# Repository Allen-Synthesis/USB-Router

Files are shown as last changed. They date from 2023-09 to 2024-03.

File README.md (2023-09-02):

# USB Router
### A module to route a USB signal between the front and back of your Eurorack system with optional +5V rail power

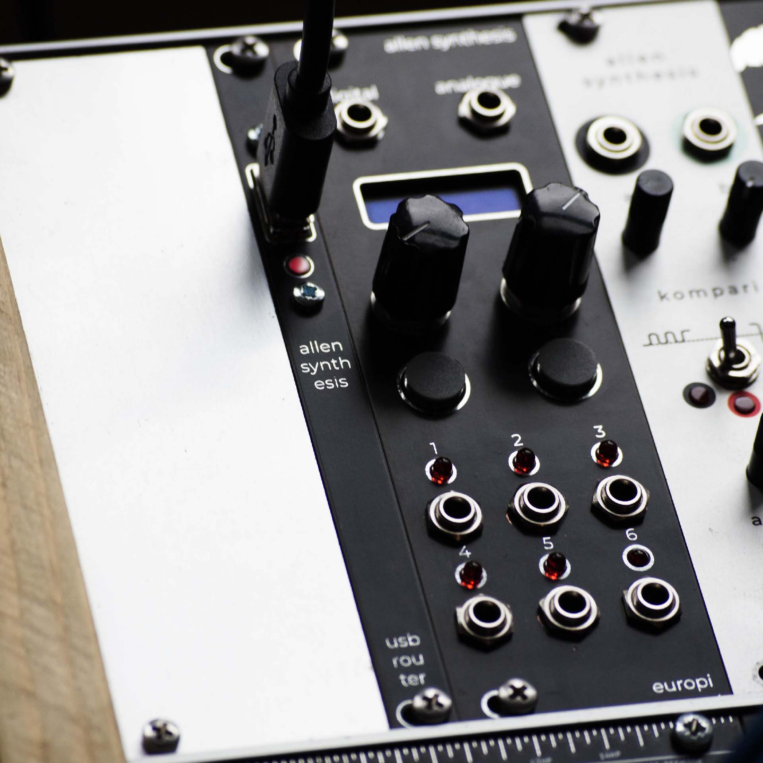
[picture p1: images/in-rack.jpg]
module in rack


The USB Router features one USB-A socket on the front, and an identical USB-A socket on the back.  
The power and data lines of the two sockets are always connected to each other, so you can always use the module for its most basic functions - programming Eurorack modules which feature USB connectors on the back.

### +5V Rail Power
There is a solder jumper on the rear of the USB Router which, if bridged with solder, will power both the front and back USB sockets using the +5V rail of your Eurorack system. This connection happens through a Schottky diode with a small voltage drop, so your +5V rail is still protected from reverse powering via the USB sockets (plugging a USB cable in which supplies +5V can never power the +5V rail of your system, only the other way around).  
This feature allows you to use the USB Router to power 5V devices, for example MIDI keyboards or lighting, or even to charge your phone.

### Potential Uses
- Programming or updating [EuroPi](https://github.com/Allen-Synthesis/EuroPi) modules or other USB supporting modules such as [Uncertainty](https://oamodular.org/products/uncertainty) by OA Modular, without needing to remove them from the rack
- Powering a MIDI keyboard such as an Arturia Keystep
- Configuring a MIDI keyboard, for example the Arturia Keystep without having to rearrange your whole setup

### LICENSES
Hardware: [CERN-OHL-S-2.0](https://spdx.org/licenses/CERN-OHL-S-2.0.html)  
Documentation: [CC0](https://creativecommons.org/share-your-work/public-domain/cc0/)

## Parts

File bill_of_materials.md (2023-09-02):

| Component | Quantity | Link | Notes |
| --- | --- | ---- | ----- |
| Panel + PCB | 1 | [Allen Synthesis](https://allensynthesis.square.site/product/usb-router/22)  | This can be bought as part of a Panel + PCB kit from the [Allen Synthesis website](https://www.allensynthesis.co.uk) or ordered using the KiCad files in this repository |
| USB-A Connector | 2 | [CPC](https://cpc.farnell.com/multicomp/usb-a-s-vt/usb-2-0-type-a-receptacle-th/dp/CN22155?ost=cn22155), [Mouser](https://www.mouser.co.uk/ProductDetail/CUI-Devices/UJ2-AV-1-TH?qs=5mqXD9RfOg2GaIS%2FC2TmTA%3D%3D) | Other vertical USB-A connectors may work, however only this one has been confirmed to fit on the PCB |
| Shrouded 16 Pin Header | 1 | [CPC](https://cpc.farnell.com/amphenol/t821116a1s100ceu/header-vertical-2-54mm-16way/dp/CN16429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), [CPC Alternative](https://cpc.farnell.com/wurth-elektronik/61201621621/header-2-54mm-vertical-16way/dp/CN17032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), [Thonk](https://www.thonk.co.uk/shop/eurorack-diy-essentials/), [Mouser](https://www.mouser.co.uk/ProductDetail/Wurth-Elektronik/61201621621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) | These headers are standard for Eurorack power connectors so can be bought from many different places |
| M3 13mm Standoff | 2 | [CPC](https://cpc.farnell.com/ettinger/05-03-133/spacer-m3x13-ni/dp/PC02612?st=13mm%20standoff), [Mouser](https://www.mouser.co.uk/ProductDetail/Wurth-Elektronik/970130321?qs=wr8lucFkNMVzI4gY2uBL%252BQ%3D%3D) | Any M3 13mm standoff will work, made of pretty much any material. As long as your screws and standoff match in pitch and the length is 13mm, they'll work |
| M3 Screw | 4 (+ 2 more if you haven't already got some to mount the module to your rails) | [CPC (100 pack)](https://cpc.farnell.com/unbranded/m3x6-pan-pozi-stainl/m3x6-pan-pozi-stainless-screws/dp/FN00814?st=m3%20screw), [Mouser](https://www.mouser.co.uk/ProductDetail/Keystone-Electronics/9191-3?qs=wOxb8XianXjYu0m25ZR3Hw%3D%3D) | These are the same screws as you use to attach your modules to the rails, so if you already have them then there's no need to order more for this module |
| 3mm Flat Top LED | 1 | [CPC](https://cpc.farnell.com/kingbright/l-424idt/led-flat-top-3mm-he-red/dp/SC11543?st=kingbright%20led%203mm), [Thonk](https://www.thonk.co.uk/shop/new-style-flat-top-leds-turing-pulses-vactrol-mix/), [Mouser](https://www.mouser.co.uk/ProductDetail/Kingbright/WP424IDT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) | These don't have to be flat-top if you have any other 3mm LEDs (of any colour) but these are the only ones I have calculated the brightness for and tested in the module |
| 4.7k Resistor | 1 | [CPC (50 pack)](https://cpc.farnell.com/unbranded/mf25-4k7/resistor-0-25w-1-4k7/dp/RE03757?st=4k7%20resistor), [Mouser](https://www.mouser.co.uk/ProductDetail/Vishay-BC-Components/SFR2500004701JA500?qs=ClR5yMXwuUeHolVbK4G8uQ%3D%3D) | Any 4.7k resistor at all will do, of any reasonable tolerance. You can also use higher or lower values for brighter or dimmer LED appearance, but 4.7k with the LEDs listed in this bill of materials are the only ones which have been tested |
| Schottky Diode | 1 | [CPC](https://cpc.farnell.com/stmicroelectronics/bat48/diode-schottky-small-signal/dp/SC07328), [Mouser](https://www.mouser.co.uk/ProductDetail/Micro-Commercial-Components-MCC/1N5817-TP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) | This can be any Schottky diode which fits, however if you want the +5V rail to power the USB sockets with a high enough voltage to meet USB specifications, then a low voltage drop (the linked diode has an acceptable drop of 400mV) is required |
| USB-A to USB-A Cable | 1 | [CPC](https://cpc.farnell.com/pro-signal/psg91428/lead-usb2-0-a-male-a-male-grey/dp/CS30623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), [Mouser](https://www.mouser.co.uk/ProductDetail/Qualtek/3021059-01M?qs=MLItCLRbWsylgGXE0uMn3Q%3D%3D) | This is completely optional, but if you want to use the USB Router to program a EuroPi or other USB supporting module, then you'll probably need one of these to be able to connect your computer to the front USB socket |
| Micro USB Cable | 1 | [CPC](https://cpc.farnell.com/pro-signal/psg91567/lead-usb-a-male-micro-b-male-white/dp/CS32737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), [Mouser](https://www.mouser.co.uk/ProductDetail/Raspberry-Pi/SC0732?qs=T%252BzbugeAwjgDO%252BS%252B%252Bwhihw%3D%3D) | This is also optional, but you will need it for programming a EuroPi if you haven't already got one |

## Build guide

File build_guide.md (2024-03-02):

# USB Router Build Guide
### This module *does require this build guide*. Seriously, do not try to build it without, the order of soldering is very important in making it actually possible to assemble.
Okay, warning out of the way, this is a pretty easy build, but because of the way the USB sockets have to slot through the front panel, this build guide must be followed accurately and in order if you want your build to go smoothly.  

# Assembly

### 1. Collect together all of the components in the [Bill of Materials](bill_of_materials.md)

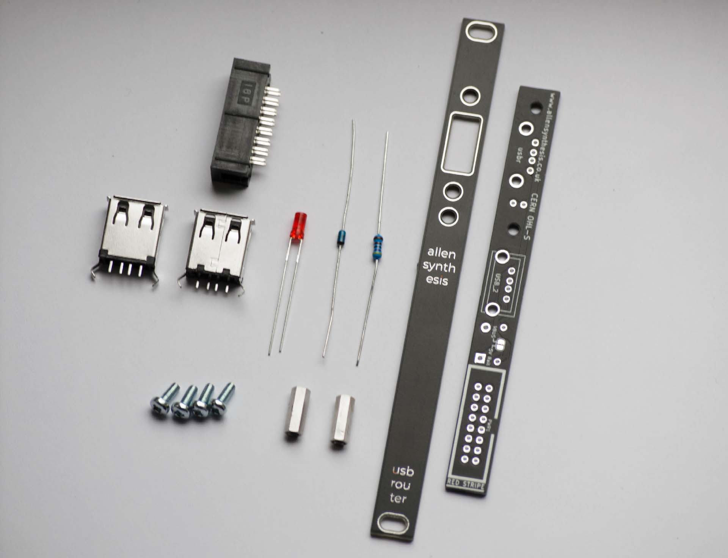
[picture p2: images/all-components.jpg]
all components


### 2. Press the 16 pin shrouded Eurorack power header into place on the side of the PCB with a small marking that says "PWR1" and a marking at the end saying "RED STRIPE"

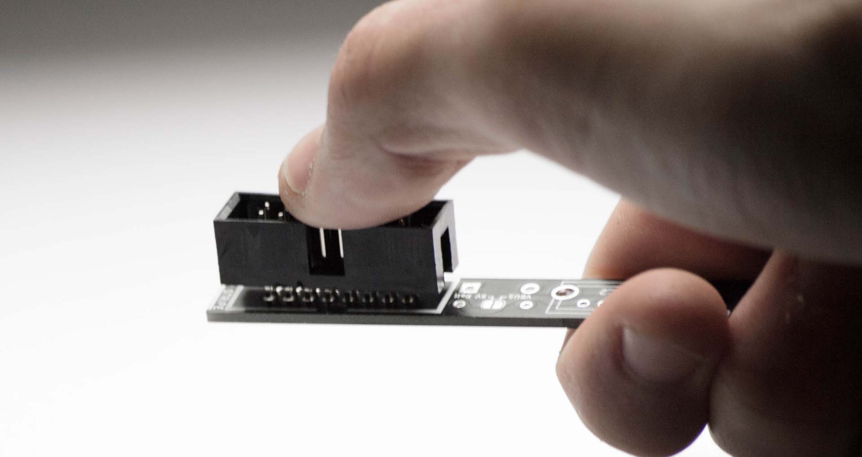
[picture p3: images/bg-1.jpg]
press the power header into the pcb


### 3. Press the back USB-A connector into the PCB footprint marked "USB_2" until it clicks into place

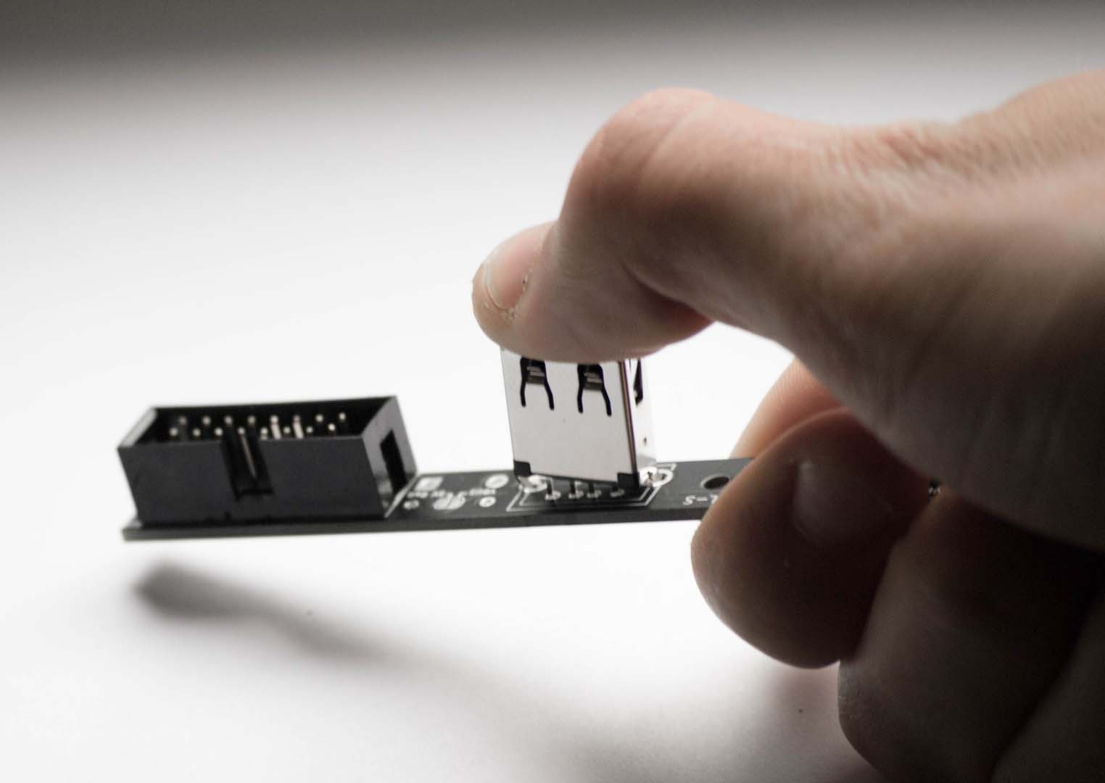
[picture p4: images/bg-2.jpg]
press the back usb-a connector into the pcb


### 4. Use an elastic band to hold the USB-A connector firmly in place

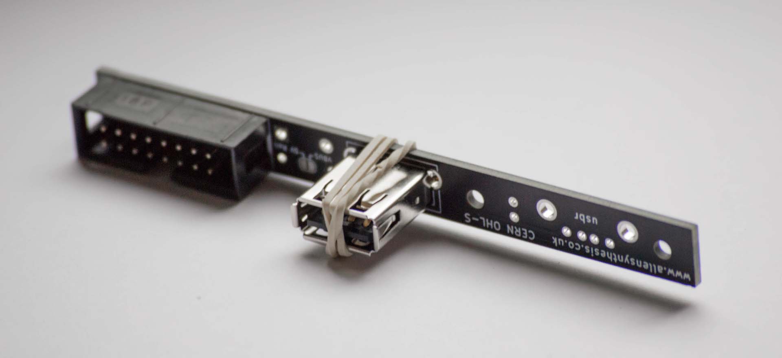
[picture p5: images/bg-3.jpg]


### 5. Solder all of the pins on the power header, and *only the two big lugs* on the USB-A connector, not any of the 4 pins in the middle

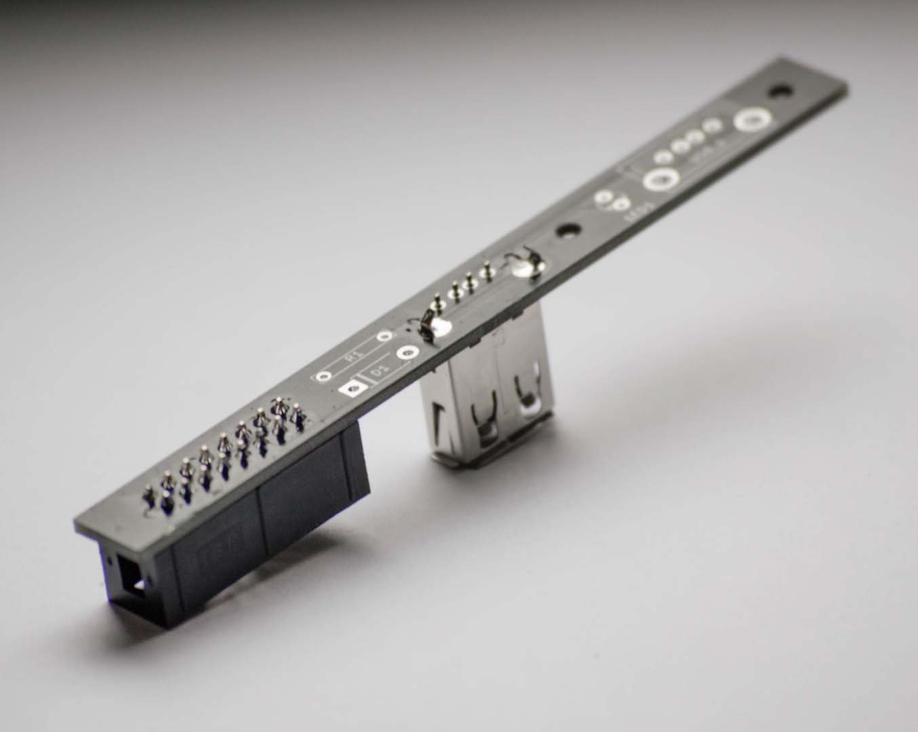
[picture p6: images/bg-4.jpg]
soldered components


### 6. After soldering the two big lugs on the USB-A connector, remove the elastic band, make sure that the connector is on straight, and only then solder the 4 pins in the middle

### 7. Push the resistor into the footprint labelled "R1" and the diode into the footprint labelled "D1". Make sure the line on the diode itself lines up with the line on the PCB

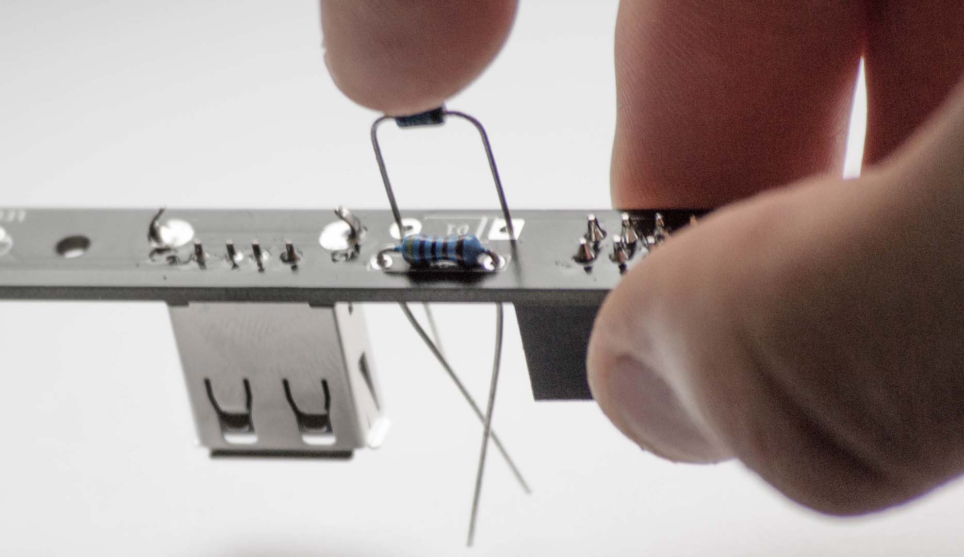
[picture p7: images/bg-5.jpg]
resistor and diode in place


### 8. Solder the resistor and the diode, and then flip the PCB over and snip off their legs

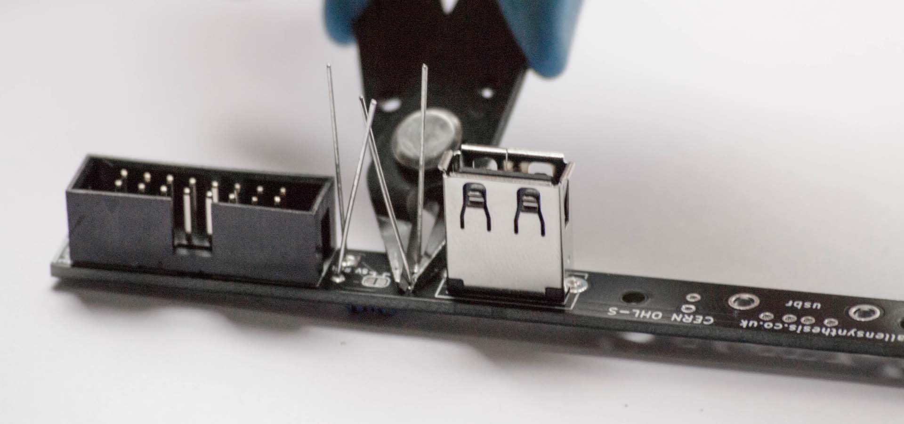
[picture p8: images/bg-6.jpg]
snipping legs


### 9. Now, if you want the +5V rail of your Eurorack power supply to power the USB sockets, then use a small amount of solder to bridge the two small pads labelled "VBUS" and "5V RAIL". If you leave this disconnected, the module will still transfer power and data between the two USB sockets, but they will not be powered by your +5V rail

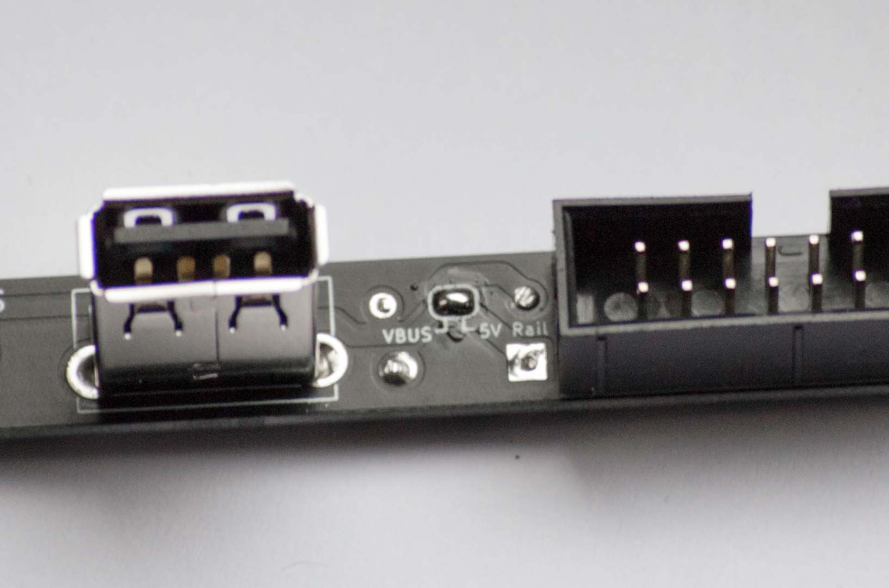
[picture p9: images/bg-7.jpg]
solder jumper


### 10. Line up the second USB-A connector with the PCB footprint labelled "USB-1" but don't push it in, just orient it so that the 4 smaller middle pins are lined up with the holes in the PCB

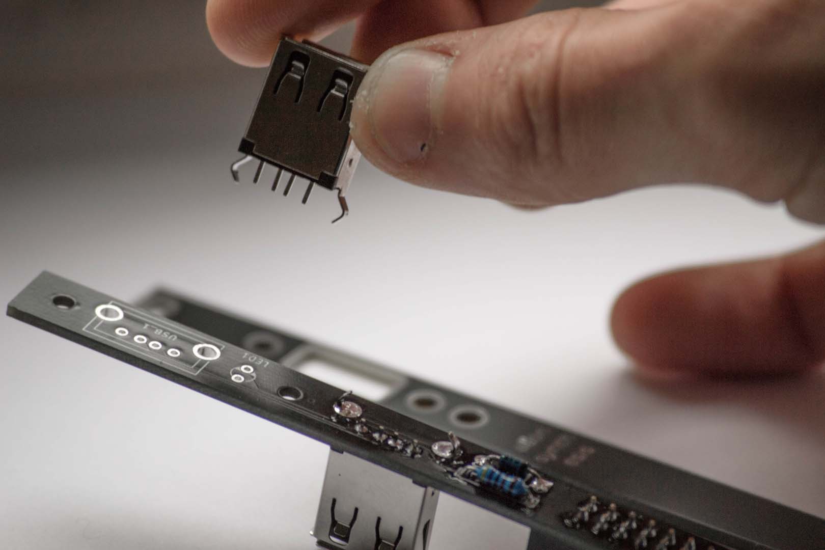
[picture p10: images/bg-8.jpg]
lining up usb connector


### 11. Now push the USB-A connector through the front panel in this orientation. You might need to slightly bend the two big lugs inward to make it fit through, and then bend them out again once it's through

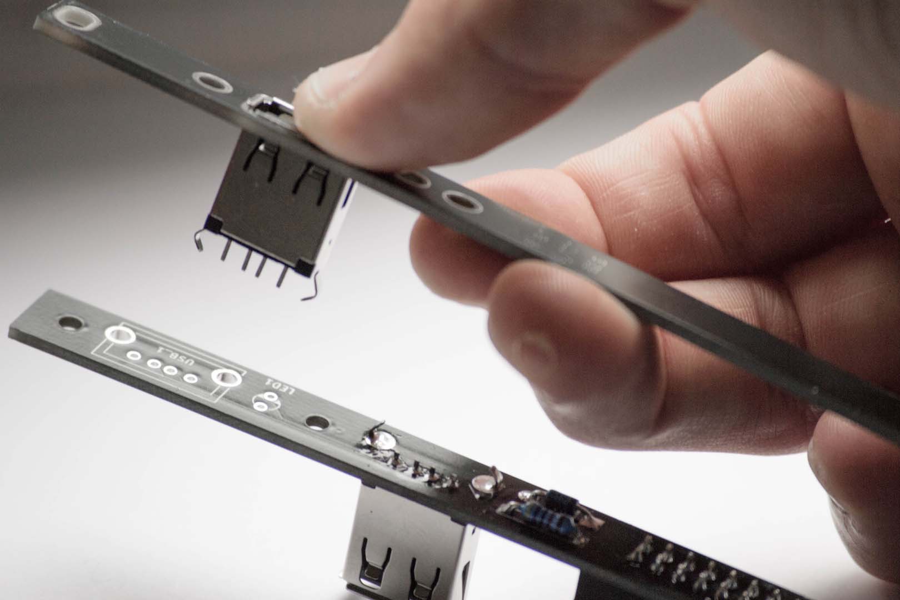
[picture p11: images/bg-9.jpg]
pushing usb connector through the panel


### 12. Push the LED into the footprint labelled "LED1". IMPORTANT: If your PCB just says "usbr" underneath where it says "www.allensynthesis.co.uk" then you need to insert the LED 'backwards' i.e. with the short pin going into the footprint hole without the white stripe. If instead your PCB reads "usbr v2.0", insert it the normal way with the short pin going into the hole with the white stripe

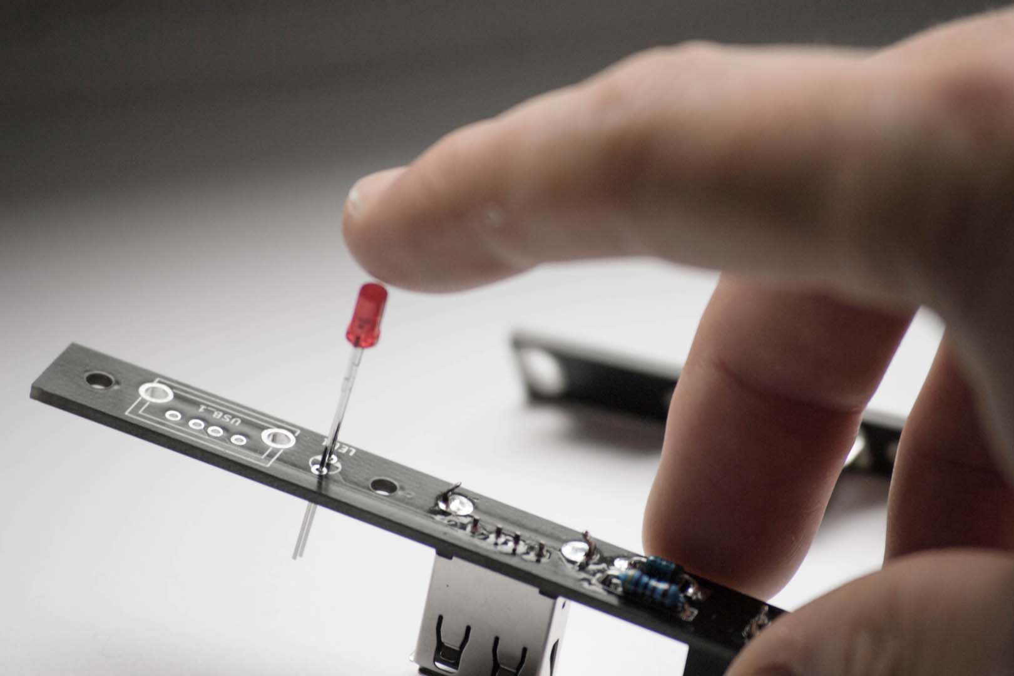
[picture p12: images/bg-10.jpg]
pressing led into pcb


### 13. Press the USB-A socket which you just pushed through the panel into its footprint, labelled "USB_1"

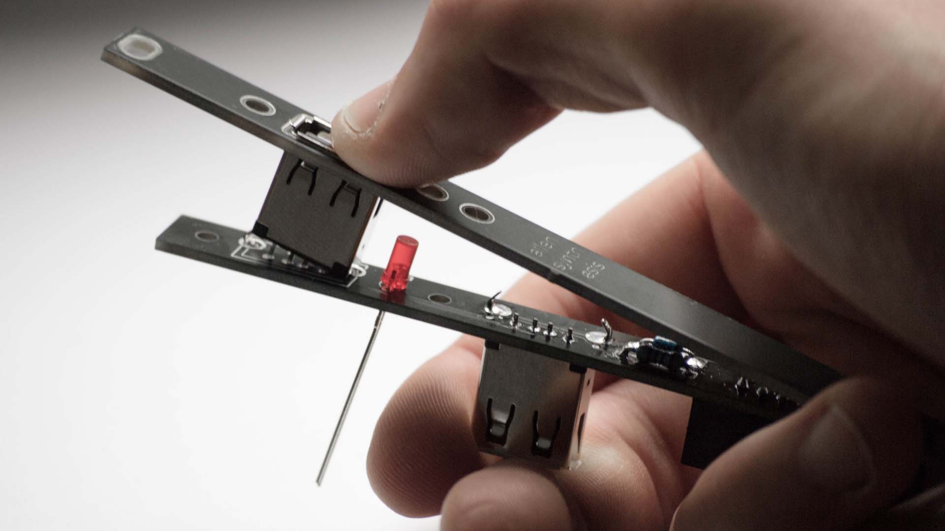
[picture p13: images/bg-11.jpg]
pressing the usb connector into the pcb


### 14. Use an elastic band again to hold it in place, and then solder the two big lugs again, then remove the elastic band and solder the 4 smaller middle pins

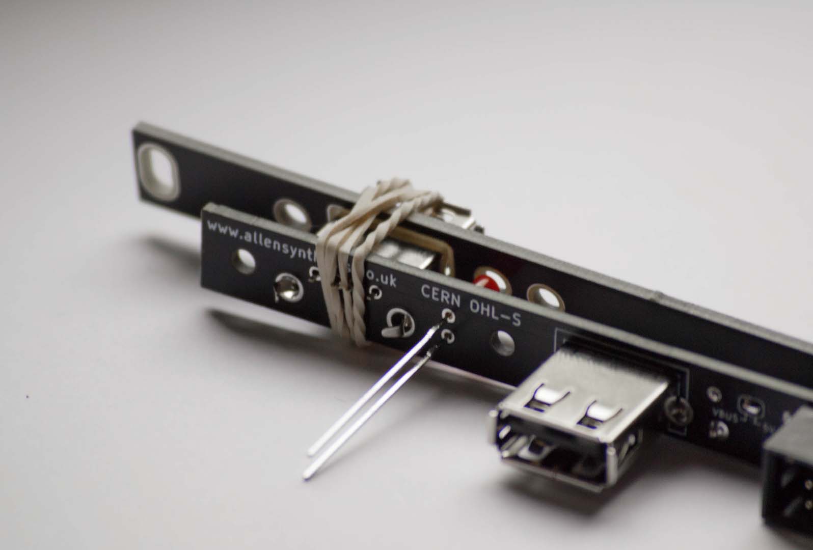
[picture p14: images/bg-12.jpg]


### 15. Now insert the lower 13mm standoff and screw it in, using two M3 screws, through both the front of the front panel, and the back of the PCB. *NOTE: If your PCB just reads 'usbr' and your standoff is M3, you will need to push the screw quite hard from the back as you turn. It is perfectly safe to do this, but it might require a little effort to get the screw to begin cutting its way through the hole. If your PCB reads 'usbr v2.0' then the hole is large enough that this isn't required*

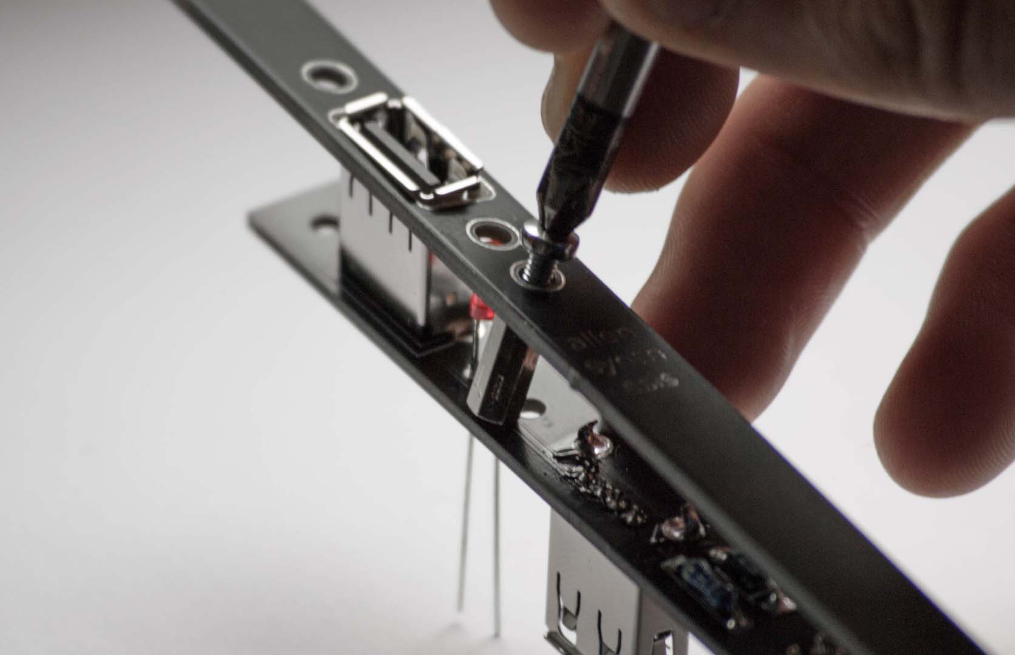
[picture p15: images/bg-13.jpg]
screwing in the standoff


### 16. Now you can press the flat top of the LED (or the domed top if you chose to buy different ones, this step is purely aesthetic) flush with the front panel, and splay the legs out slightly to kepe it in place

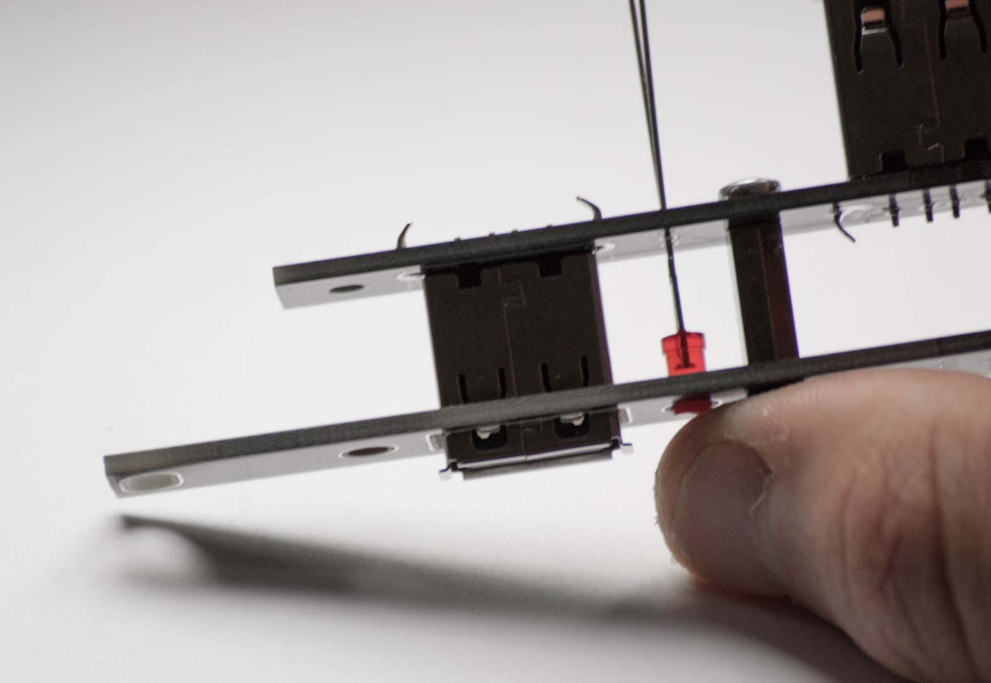
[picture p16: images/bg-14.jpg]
pressing the led flush


### 17. Solder the LED legs, then turn over the PCB and snip off the excess

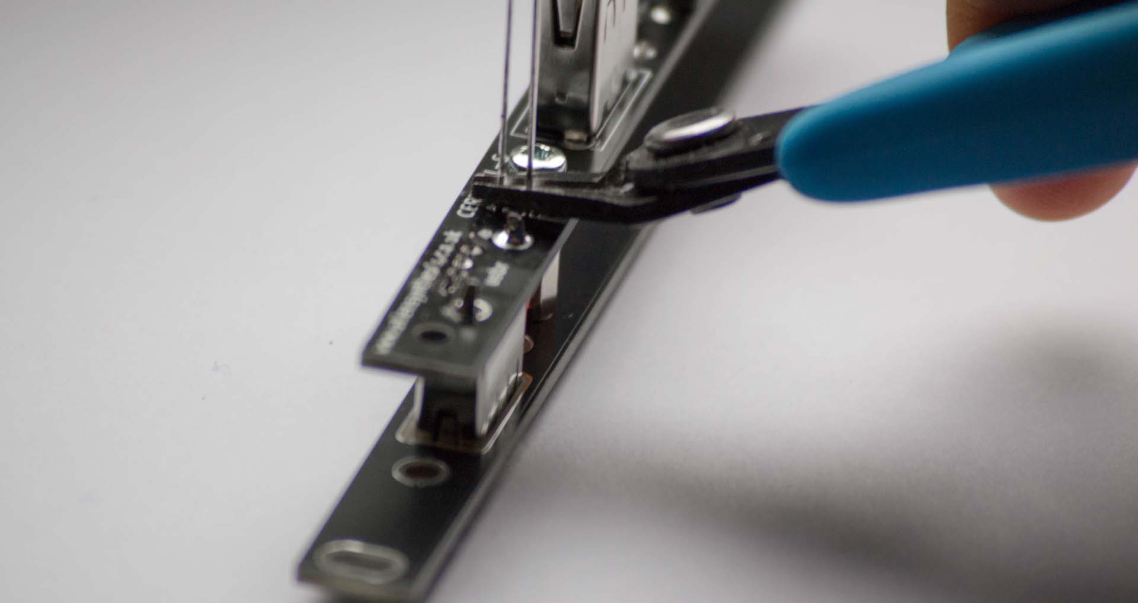
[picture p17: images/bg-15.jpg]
snipping the leads


### 18. Finally screw in the upper 13mm standoff using two M3 screws through the front and back. Follow the advice in step 15 if your PCB reads 'usbr' instead of 'usbr v2.0' again

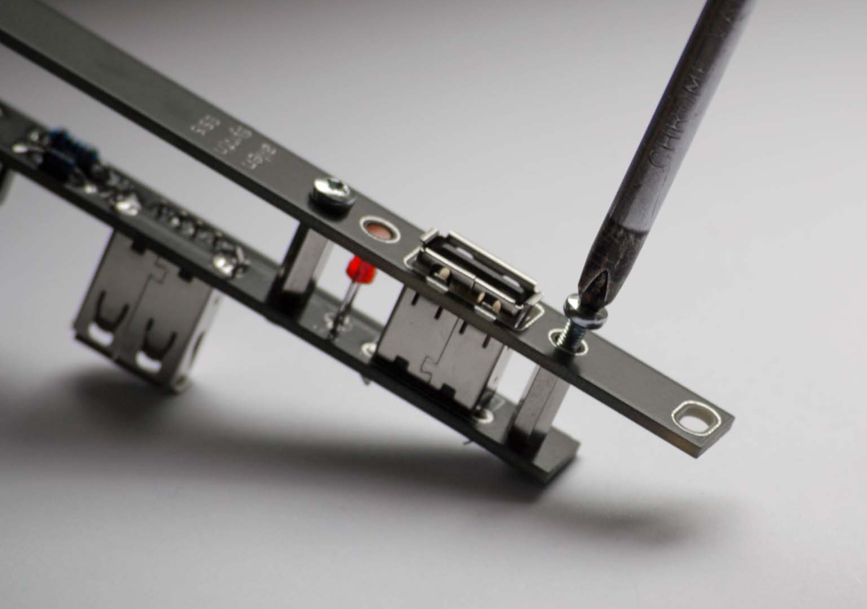
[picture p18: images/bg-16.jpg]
screwing in the other standoff


# Testing
### Test that there is no continuity between the top and bottom out of the smaller 4 pins of the top USB socket

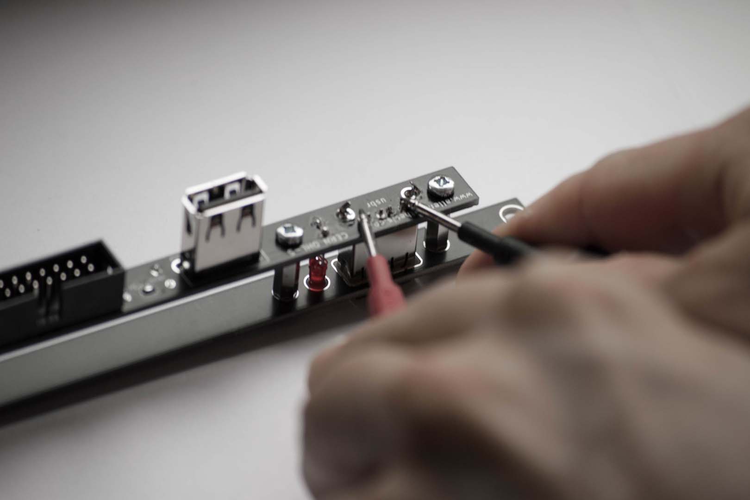
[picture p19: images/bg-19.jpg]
pressing in the power cable


### If you chose to solder the solder jumper and connect your +5V rail to the sockets, then plug your USB Router into your Eurorack system with no other modules plugged in

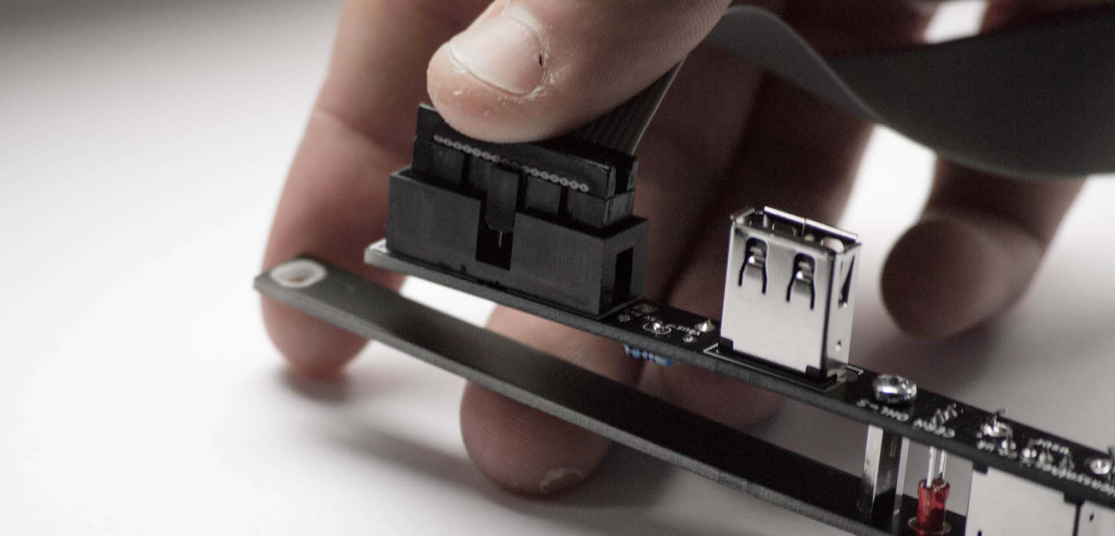
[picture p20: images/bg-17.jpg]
power cable connected


### Turn on your power supply, and test the same two pins as before, but this time using a voltmeter

testing continuity

### If the voltage reads anywhere outside the range 4.4V-5.5V, then *do not* connect this module to any other USB capable module, or to a computer, until you have checked all your solder joints and components, and remedied whatever was causing this voltage difference. You could permanently damage any other modules or computer connected if the voltage reads outside this range

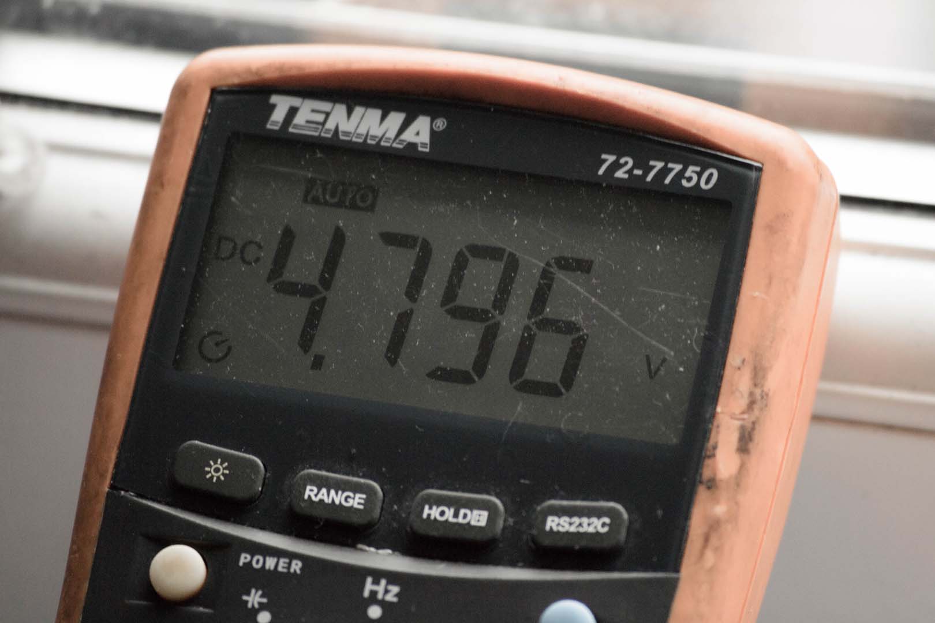
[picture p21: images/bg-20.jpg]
voltage range on a voltmeter


# Enjoy your build!
Well done for assembling an Allen Synthesis USB Router, mount it in your case and use as you please!  
Tag us in any posts on Instagram to show off your new build, or post about it in the Discord server.

completed build

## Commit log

2023-04-14 kicad save
    [usb-router.kicad_pcb, usb-router.kicad_sch]
2023-04-14 rename folder
    [usb-router.kicad_pcb, usb-router.kicad_sch]
2023-04-14 create 1u
    [usb-router-1u.kicad_pcb, usb-router-1u.kicad_sch, usb-router.kicad_pcb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]
2023-08-12 add panel
    [usb-router-panel.kicad_pcb]
2023-08-31 fix LED orientation
    [usb-router.kicad_pcb, usb-router.kicad_sch]
2023-09-01 rearrange folders
    [usb-router-1u.kicad_pcb, usb-router-1u.kicad_sch, usb-router-panel.kicad_pcb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]
2023-09-01 fix screw link
2023-09-01 fix micro usb cable link
2023-09-17 Add standoff note
2024-02-25 widen panel holes
    [usb-router-panel.kicad_pcb]
2024-03-02 Fix link to BOM in build_guide.md
